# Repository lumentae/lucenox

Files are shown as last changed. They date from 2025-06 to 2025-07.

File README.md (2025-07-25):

# Lucenox

**Lucenox** — *Light in the Darkness*

---

## Overview

Lucenox is a custom mechanical keyboard with hotswappable switches which was inspired by the QWERTZ layout. It also features per key RGB with QMK!

---

## Reason

I made the project just for fun and to see if I could build my own keyboard, because I wanted something that felt exactly like my current keyboard, but in a smaller size.
Also I currently use a membrane keyboard and I thought that highway could give me an opportunity to learn how mechanical keyboards work and switch to a mechanical one.

---

## Technical Details

- **Microcontroller:** Raspberry Pi Pico 
- **Firmware:** QMK
- **Connectivity:** USB wired connection
- **LEDs:** SK6812 RGB underglow LEDs with individual addressability

---

## Front
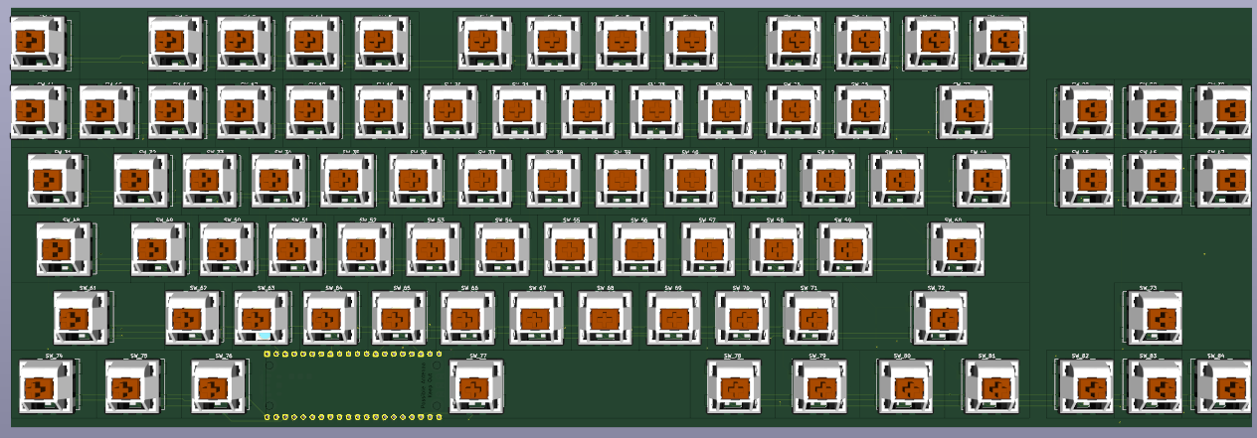
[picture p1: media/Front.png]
Front


## Back
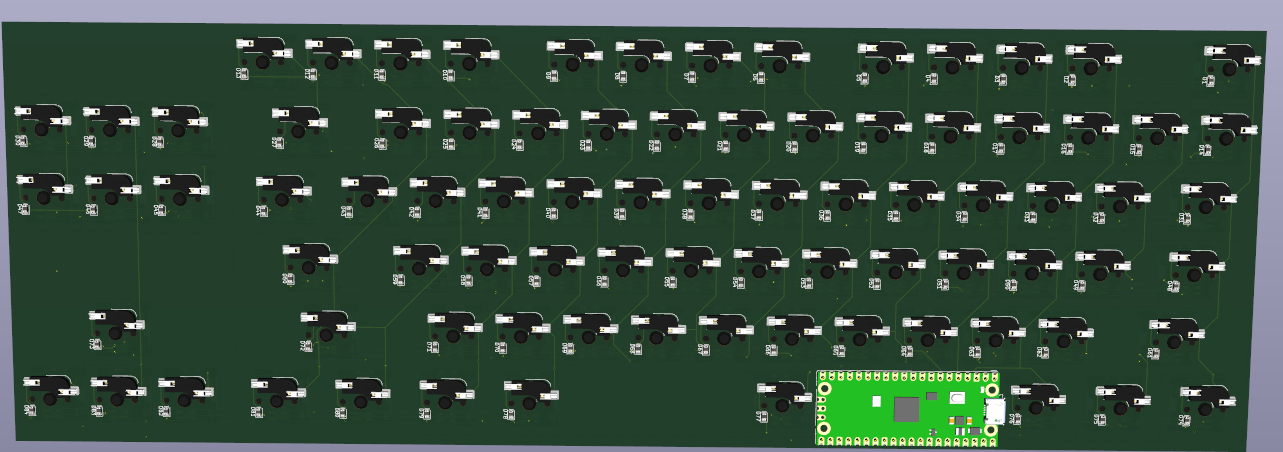
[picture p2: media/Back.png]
Back


## Schematic
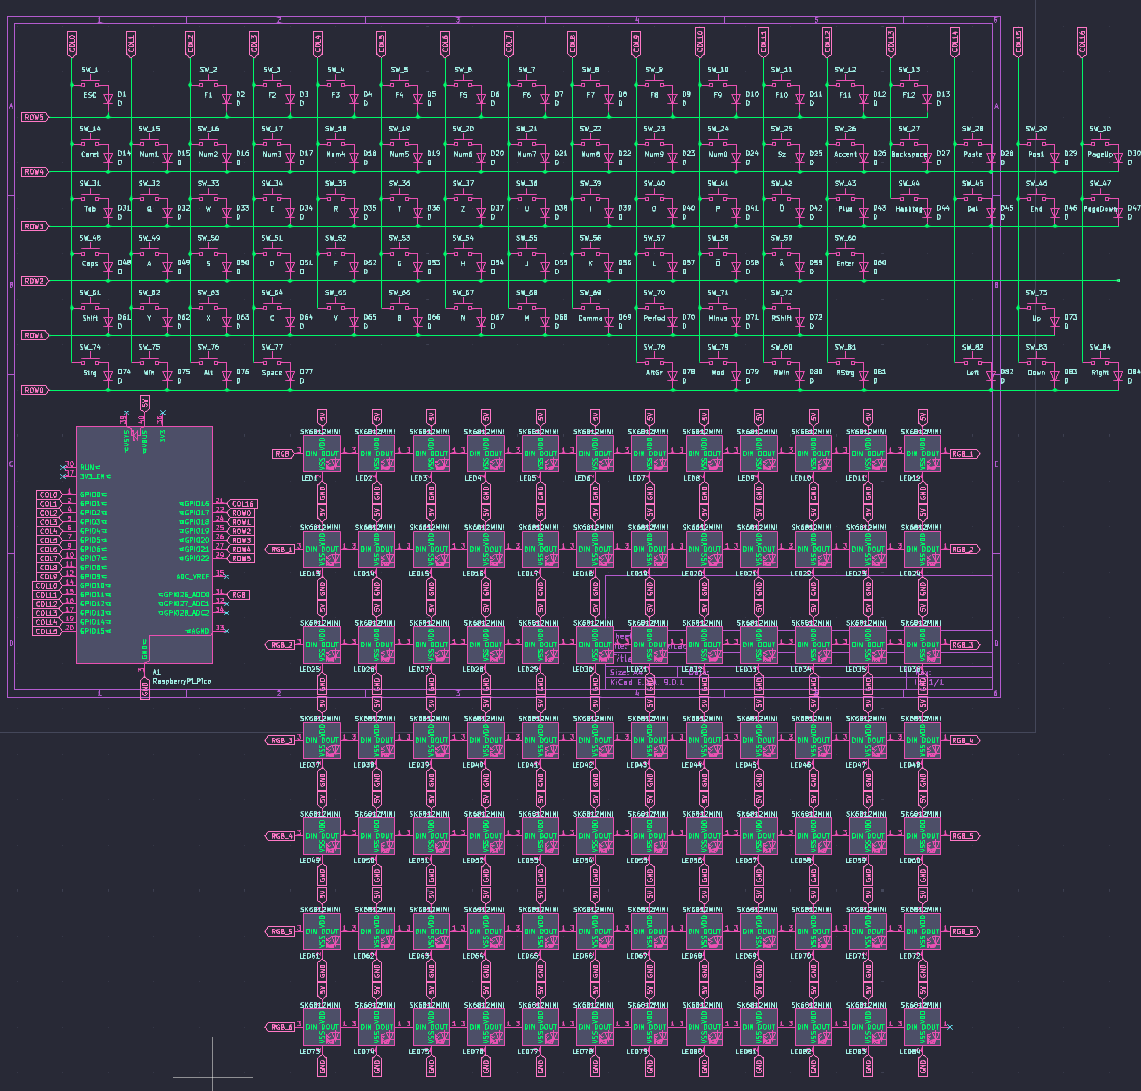
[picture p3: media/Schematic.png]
Schematic


## Case
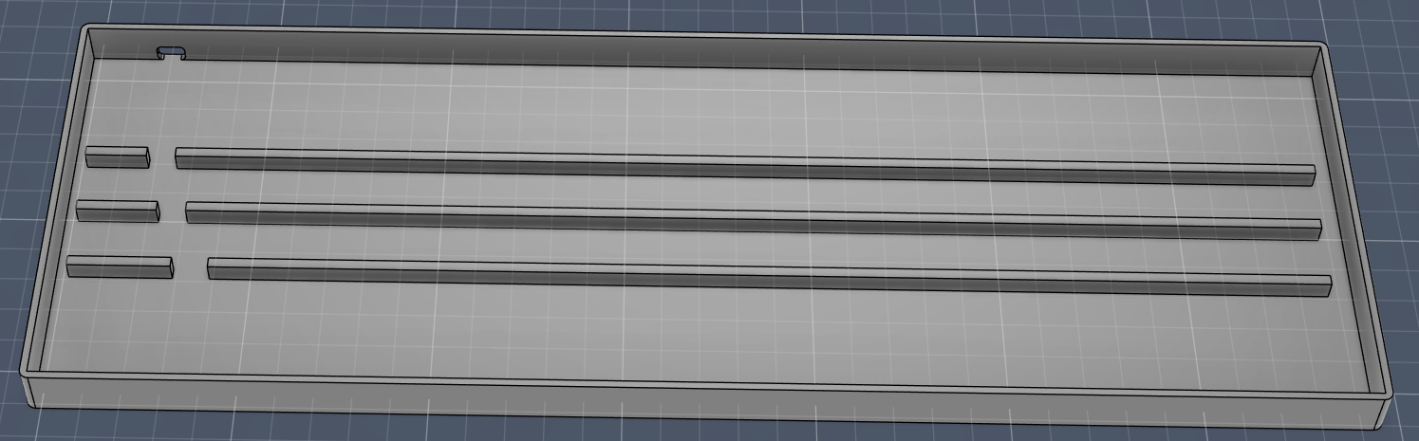
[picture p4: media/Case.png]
Case


## BOM
Quantity  | Name                   | Link                                                                                                     | Price + Shipping
--------- | ---------------------- | -------------------------------------------------------------------------------------------------------- | ----------------
3*30 (90) | Cherry MX Switch       | https://aliexpress.com/item/1005006578935785.html                                                        | 25.17€
84 (90)   | Kailh Hotswap Sockets  | https://candykeys.com/product/kailh-hot-swap-pcb-socket-black                                            | 16.00€
84 (85)   | SK6812MINI LED         | https://lcsc.com/product-detail/RGB-LEDs-Built-in-IC_OPSCO-Optoelectronics-SK6812MINI-E_C5149201.html    | 4.38€
84 (100)  | 0805 Diode (D)         | https://lcsc.com/product-detail/Switching-Diodes_LIZ-Elec-CD4148WSP_C109001.html                         | 1.06€
1         | LCSC Fees              | -                                                                                                        | 9.58€
1         | Raspberry Pi Pico      | https://aliexpress.com/item/1005007384675543.html                                                        | 2.79€
1         | Keycaps                | https://aliexpress.com/item/1005006484466863.html                                                        | 20.99€
1         | PCB (without coupon)   | -                                                                                                        | 88.11€
1         | Total                  |                                                                                                          | 168.08€

### Total
EUR     | USD     | Notes
------- | ------- | -----
168.08€ | 197.44$ | without pcb coupon
148.08€ | 173.95$ | with pcb coupon

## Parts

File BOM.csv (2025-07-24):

Category | Part | Qty | Price € | Link
Switches | Cherry MX Switch | 90 | 25.17€ | https://aliexpress.com/item/1005006578935785.html
Sockets | Kailh Hotswap Sockets | 84 | 16.00€ | https://candykeys.com/product/kailh-hot-swap-pcb-socket-black
LEDs | SK6812MINI LED | 84 | 4.38€ | https://lcsc.com/product-detail/RGB-LEDs-Built-in-IC_OPSCO-Optoelectronics-SK6812MINI-E_C5149201.html
Diodes | 0805 Diode (D) | 84 | 1.06€ | https://lcsc.com/product-detail/Switching-Diodes_LIZ-Elec-CD4148WSP_C109001.html
Fees | LCSC Fees | 1 | 9.58€
MCU | Raspberry Pi Pico | 1 | 2.79€ | https://aliexpress.com/item/1005007384675543.html
Keycaps | Keycaps | 1 | 20.99€ | https://aliexpress.com/item/1005006484466863.html
PCB | PCB (without coupon) | 1 | 88.11€
Total | Total | 1 | 168.08€

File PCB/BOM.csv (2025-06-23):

Id | Designator | Footprint | Quantity | Designation | Supplier and ref
1 | SW_76 | SW_Hotswap_Kailh_MX_1.25u | 1 | Alt
2 | SW_48 | SW_Hotswap_Kailh_MX_1.75u | 1 | Caps
3 | LED71,LED56,LED1,LED78,LED81,LED41,LED16,LED65,LED30,LED24,LED33,LED35,LED73,LED4,LED15,LED62,LED42,LED46,LED14,LED2,LED32,LED23,LED47,LED13,LED66,LED50,LED82,LED20,LED49,LED60,LED7,LED5,LED11,LED63,LED79,LED74,LED21,LED69,LED59,LED57,LED10,LED37,LED3,LED84,LED55,LED6,LED29,LED22,LED68,LED39,LED27,LED45,LED61,LED38,LED25,LED83,LED53,LED17,LED8,LED19,LED58,LED54,LED75,LED77,LED28,LED36,LED52,LED67,LED26,LED76,LED70,LED9,LED40,LED34,LED18,LED48,LED44,LED31,LED80,LED43,LED12,LED64,LED51,LED72 | LED_SK6812MINI_PLCC4_3.5x3.5mm_P1.75mm | 84 | SK6812MINI
4 | SW_12 | SW_Hotswap_Kailh_MX_1.00u | 1 | F11
5 | SW_71 | SW_Hotswap_Kailh_MX_1.00u | 1 | Minus
6 | SW_45 | SW_Hotswap_Kailh_MX_1.00u | 1 | Del
7 | SW_37 | SW_Hotswap_Kailh_MX_1.00u | 1 | Z
8 | SW_16 | SW_Hotswap_Kailh_MX_1.00u | 1 | Num2
9 | SW_60 | SW_Hotswap_Kailh_MX_2.25u | 1 | Enter
10 | SW_14 | SW_Hotswap_Kailh_MX_1.00u | 1 | Caret
11 | SW_72 | SW_Hotswap_Kailh_MX_2.75u | 1 | RShift
12 | SW_7 | SW_Hotswap_Kailh_MX_1.00u | 1 | F6
13 | SW_43 | SW_Hotswap_Kailh_MX_1.00u | 1 | Plus
14 | SW_11 | SW_Hotswap_Kailh_MX_1.00u | 1 | F10
15 | SW_24 | SW_Hotswap_Kailh_MX_1.00u | 1 | Num0
16 | SW_84 | SW_Hotswap_Kailh_MX_1.00u | 1 | Right
17 | SW_34 | SW_Hotswap_Kailh_MX_1.00u | 1 | E
18 | SW_54 | SW_Hotswap_Kailh_MX_1.00u | 1 | H
19 | SW_49 | SW_Hotswap_Kailh_MX_1.00u | 1 | A
20 | SW_19 | SW_Hotswap_Kailh_MX_1.00u | 1 | Num5
21 | SW_8 | SW_Hotswap_Kailh_MX_1.00u | 1 | F7
22 | SW_26 | SW_Hotswap_Kailh_MX_1.00u | 1 | Accent
23 | SW_13 | SW_Hotswap_Kailh_MX_1.00u | 1 | F12
24 | SW_33 | SW_Hotswap_Kailh_MX_1.00u | 1 | W
25 | SW_58 | SW_Hotswap_Kailh_MX_1.00u | 1 | Ö
26 | SW_17 | SW_Hotswap_Kailh_MX_1.00u | 1 | Num3
27 | SW_9 | SW_Hotswap_Kailh_MX_1.00u | 1 | F8
28 | SW_75 | SW_Hotswap_Kailh_MX_1.25u | 1 | Win
29 | SW_79 | SW_Hotswap_Kailh_MX_1.25u | 1 | Mod
30 | SW_62 | SW_Hotswap_Kailh_MX_1.00u | 1 | Y
31 | SW_82 | SW_Hotswap_Kailh_MX_1.00u | 1 | Left
32 | SW_66 | SW_Hotswap_Kailh_MX_1.00u | 1 | B
33 | SW_47 | SW_Hotswap_Kailh_MX_1.00u | 1 | PageDown
34 | SW_35 | SW_Hotswap_Kailh_MX_1.00u | 1 | R
35 | SW_55 | SW_Hotswap_Kailh_MX_1.00u | 1 | J
36 | SW_59 | SW_Hotswap_Kailh_MX_1.00u | 1 | Ä
37 | SW_56 | SW_Hotswap_Kailh_MX_1.00u | 1 | K
38 | SW_39 | SW_Hotswap_Kailh_MX_1.00u | 1 | I
39 | SW_28 | SW_Hotswap_Kailh_MX_1.00u | 1 | Paste
40 | SW_65 | SW_Hotswap_Kailh_MX_1.00u | 1 | V
41 | SW_57 | SW_Hotswap_Kailh_MX_1.00u | 1 | L
42 | SW_30 | SW_Hotswap_Kailh_MX_1.00u | 1 | PageUp
43 | SW_36 | SW_Hotswap_Kailh_MX_1.00u | 1 | T
44 | SW_52 | SW_Hotswap_Kailh_MX_1.00u | 1 | F
45 | SW_5 | SW_Hotswap_Kailh_MX_1.00u | 1 | F4
46 | SW_63 | SW_Hotswap_Kailh_MX_1.00u | 1 | X
47 | SW_41 | SW_Hotswap_Kailh_MX_1.00u | 1 | P
48 | SW_74 | SW_Hotswap_Kailh_MX_1.25u | 1 | Strg
49 | SW_51 | SW_Hotswap_Kailh_MX_1.00u | 1 | D
50 | SW_2 | SW_Hotswap_Kailh_MX_1.00u | 1 | F1
51 | SW_61 | SW_Hotswap_Kailh_MX_2.25u | 1 | Shift
52 | SW_78 | SW_Hotswap_Kailh_MX_1.25u | 1 | AltGr
53 | SW_68 | SW_Hotswap_Kailh_MX_1.00u | 1 | M
54 | SW_53 | SW_Hotswap_Kailh_MX_1.00u | 1 | G
55 | SW_69 | SW_Hotswap_Kailh_MX_1.00u | 1 | Comma
56 | SW_29 | SW_Hotswap_Kailh_MX_1.00u | 1 | Pos1
57 | SW_50 | SW_Hotswap_Kailh_MX_1.00u | 1 | S
58 | SW_20 | SW_Hotswap_Kailh_MX_1.00u | 1 | Num6
59 | SW_15 | SW_Hotswap_Kailh_MX_1.00u | 1 | Num1
60 | SW_32 | SW_Hotswap_Kailh_MX_1.00u | 1 | Q
61 | SW_1 | SW_Hotswap_Kailh_MX_1.00u | 1 | ESC
62 | SW_83 | SW_Hotswap_Kailh_MX_1.00u | 1 | Down
63 | SW_81 | SW_Hotswap_Kailh_MX_1.25u | 1 | RStrg
64 | SW_44 | SW_Hotswap_Kailh_MX_1.50u | 1 | Hashtag
65 | SW_23 | SW_Hotswap_Kailh_MX_1.00u | 1 | Num9
66 | SW_18 | SW_Hotswap_Kailh_MX_1.00u | 1 | Num4
67 | SW_40 | SW_Hotswap_Kailh_MX_1.00u | 1 | O
68 | SW_67 | SW_Hotswap_Kailh_MX_1.00u | 1 | N
69 | SW_3 | SW_Hotswap_Kailh_MX_1.00u | 1 | F2
70 | SW_42 | SW_Hotswap_Kailh_MX_1.00u | 1 | Ü
71 | SW_27 | SW_Hotswap_Kailh_MX_2.00u | 1 | Backspace
72 | SW_4 | SW_Hotswap_Kailh_MX_1.00u | 1 | F3
73 | SW_64 | SW_Hotswap_Kailh_MX_1.00u | 1 | C
74 | SW_80 | SW_Hotswap_Kailh_MX_1.25u | 1 | RWin
75 | SW_6 | SW_Hotswap_Kailh_MX_1.00u | 1 | F5
76 | SW_21 | SW_Hotswap_Kailh_MX_1.00u | 1 | Num7
77 | SW_77 | SW_Hotswap_Kailh_MX_6.25u | 1 | Space
78 | SW_73 | SW_Hotswap_Kailh_MX_1.00u | 1 | Up
79 | SW_46 | SW_Hotswap_Kailh_MX_1.00u | 1 | End
80 | SW_31 | SW_Hotswap_Kailh_MX_1.50u | 1 | Tab
81 | SW_38 | SW_Hotswap_Kailh_MX_1.00u | 1 | U
82 | SW_25 | SW_Hotswap_Kailh_MX_1.00u | 1 | Sz
83 | SW_10 | SW_Hotswap_Kailh_MX_1.00u | 1 | F9
84 | SW_22 | SW_Hotswap_Kailh_MX_1.00u | 1 | Num8
85 | SW_70 | SW_Hotswap_Kailh_MX_1.00u | 1 | Period
86 | D78,D36,D22,D40,D52,D26,D49,D19,D83,D5,D72,D44,D39,D6,D76,D82,D38,D74,D4,D68,D12,D48,D80,D28,D59,D81,D45,D66,D58,D2,D62,D84,D23,D10,D24,D35,D56,D31,D18,D8,D65,D64,D1,D73,D46,D30,D67,D20,D77,D63,D16,D69,D21,D3,D60,D70,D79,D61,D27,D55,D15,D75,D11,D71,D34,D47,D41,D17,D37,D43,D13,D29,D14,D42,D32,D25,D53,D7,D33,D50,D9,D51,D57,D54 | D_0805_2012Metric | 84 | D
87 | A1 | RaspberryPi_Pico_Common_THT | 1 | RaspberryPi_Pico

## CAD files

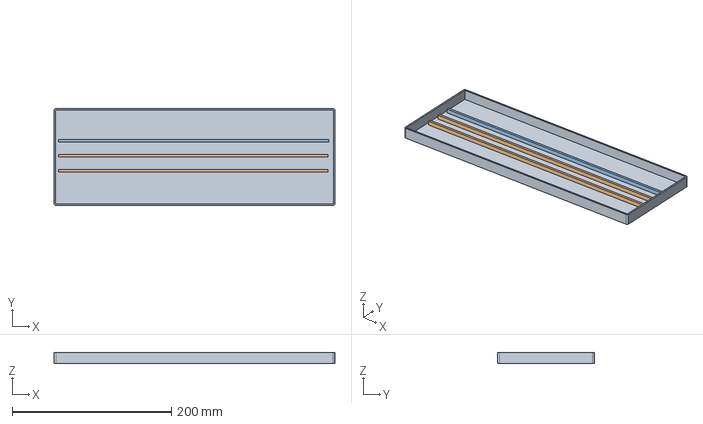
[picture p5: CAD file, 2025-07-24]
CAD/Case.step
353.0 x 122.0 x 14.0 mm

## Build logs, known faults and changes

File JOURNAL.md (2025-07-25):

---
title: "Lucenox"
author: "lumentae"
description: "Lucenox is a 75% mechanical keyboard with 84 keys, RGB underglow, and built for QWERTZ users."
created_at: "2025-06-18"
---

Total Time Spent: 19h

# 18.06
I started working on the schematic, which I got done quickly but I needed to research how keyboard matrices work and found [this](https://www.youtube.com/watch?v=7LyziNdFlew) video by Joe Scotto.

After 3h of brainstorming and designing the schematic, I moved on to the pcb.
This is what took me the longest because I tried to route it manually.
Schematic

Time spent: 6h

# 19.06
Today I remembered that I have Freerouting installed, so I used it for it's autorouting feature and it saved me many hours of painfully placing vias and routes.
I also adjusted the layout and mcu position.
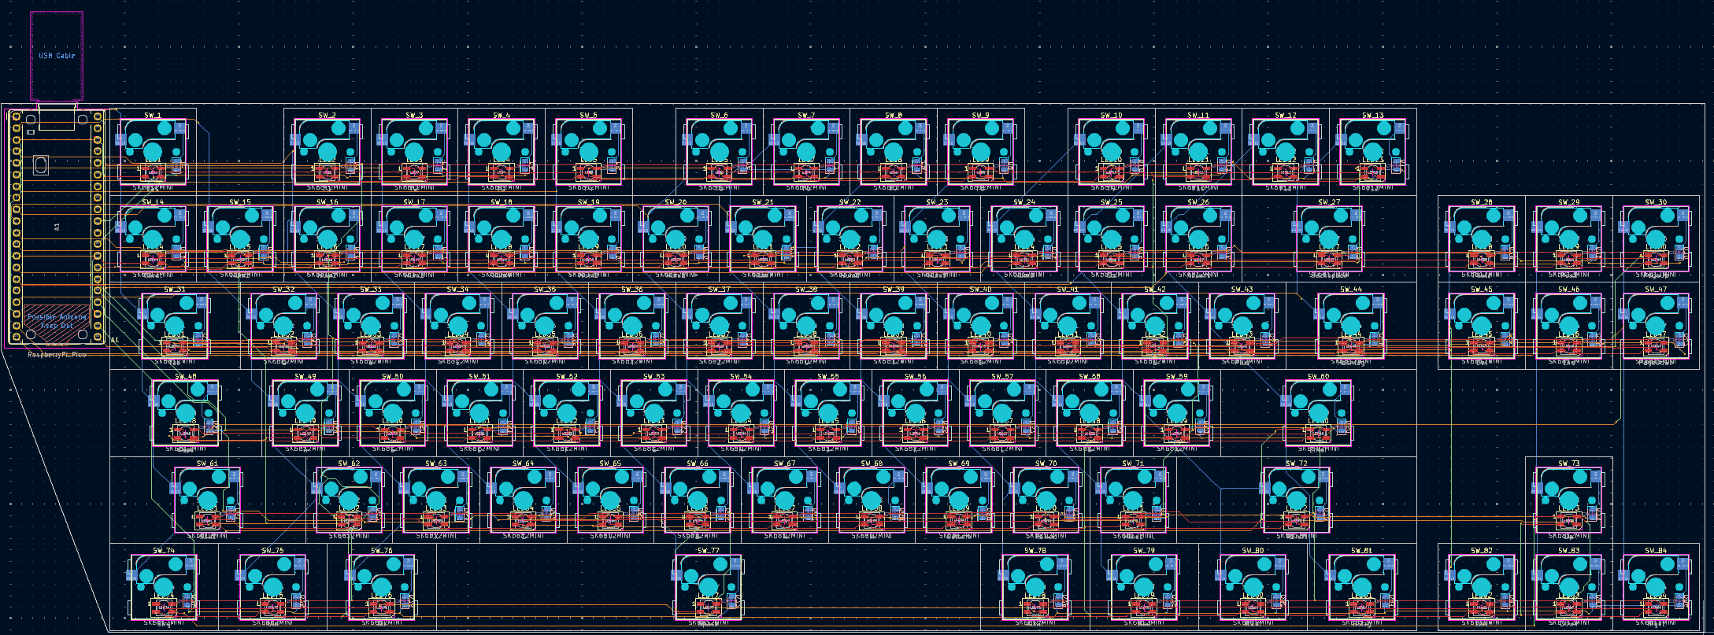
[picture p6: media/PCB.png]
PCB


Time spent: 2h

# 22.06
I placed the mcu under the space key, so that the pcb doesn't look so weird.
I'll need a longer usb cable now 🥲
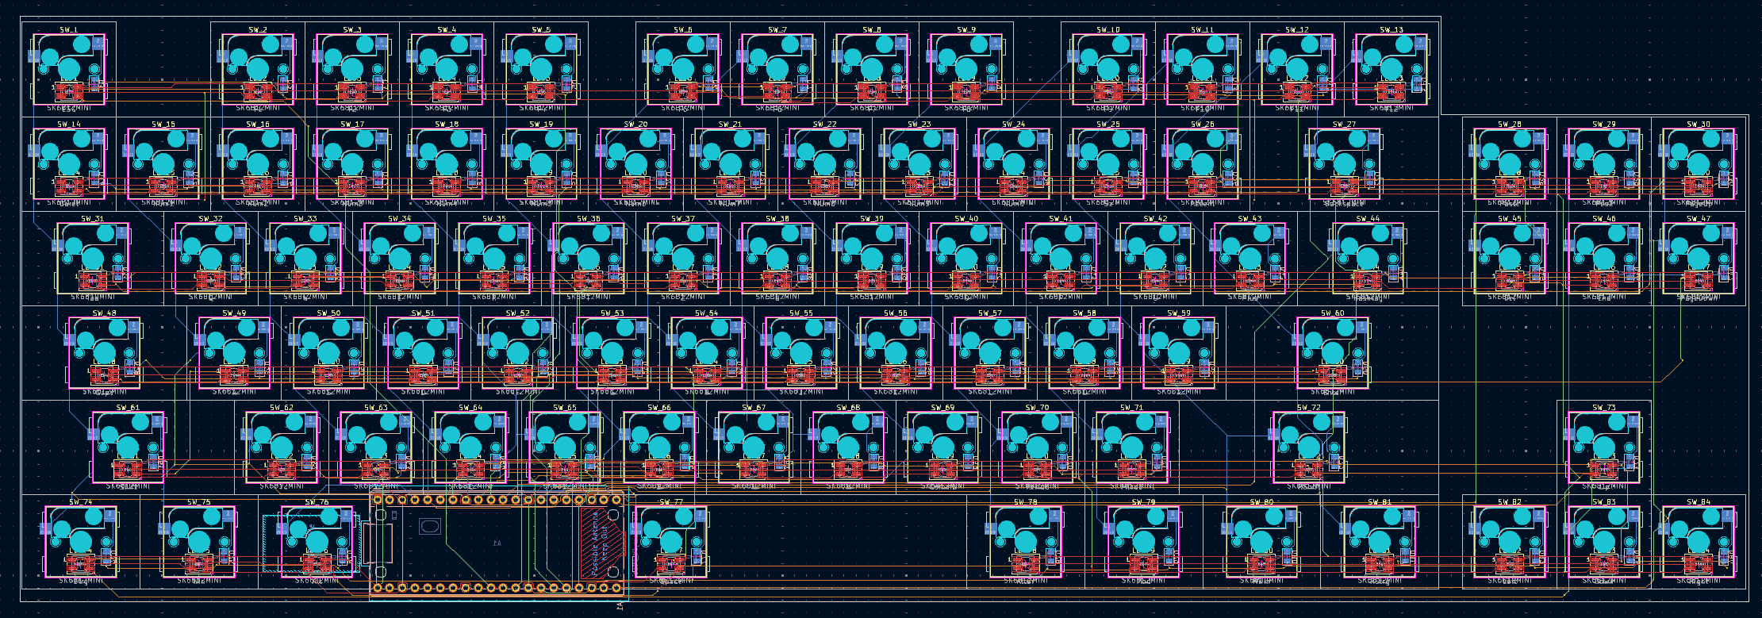
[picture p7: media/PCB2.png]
PCB2


Time spent: 1h

# 23.06
Today I worked on polishing the repo and uploading all files I used for creating the project.
Tomorrow I will work on the cad model

Time spent: 3h

# 24.07
I finished the model after 1 month because I didn't have enough motivation to finish it.
Also I didn't make a front plate because I like to look at the pcb
Case

I also modified the pcb to not have that cut out in the top right corner
PCB_Final

I finally finished the bom and I only need to make the firmware

Time spent: 4h

# 25.07
After a long trial and error session with QMK I finally managed that the firmware is building.
The QMK docs are not very good at explaining how to make your own keyboard...

Time spent: 3h

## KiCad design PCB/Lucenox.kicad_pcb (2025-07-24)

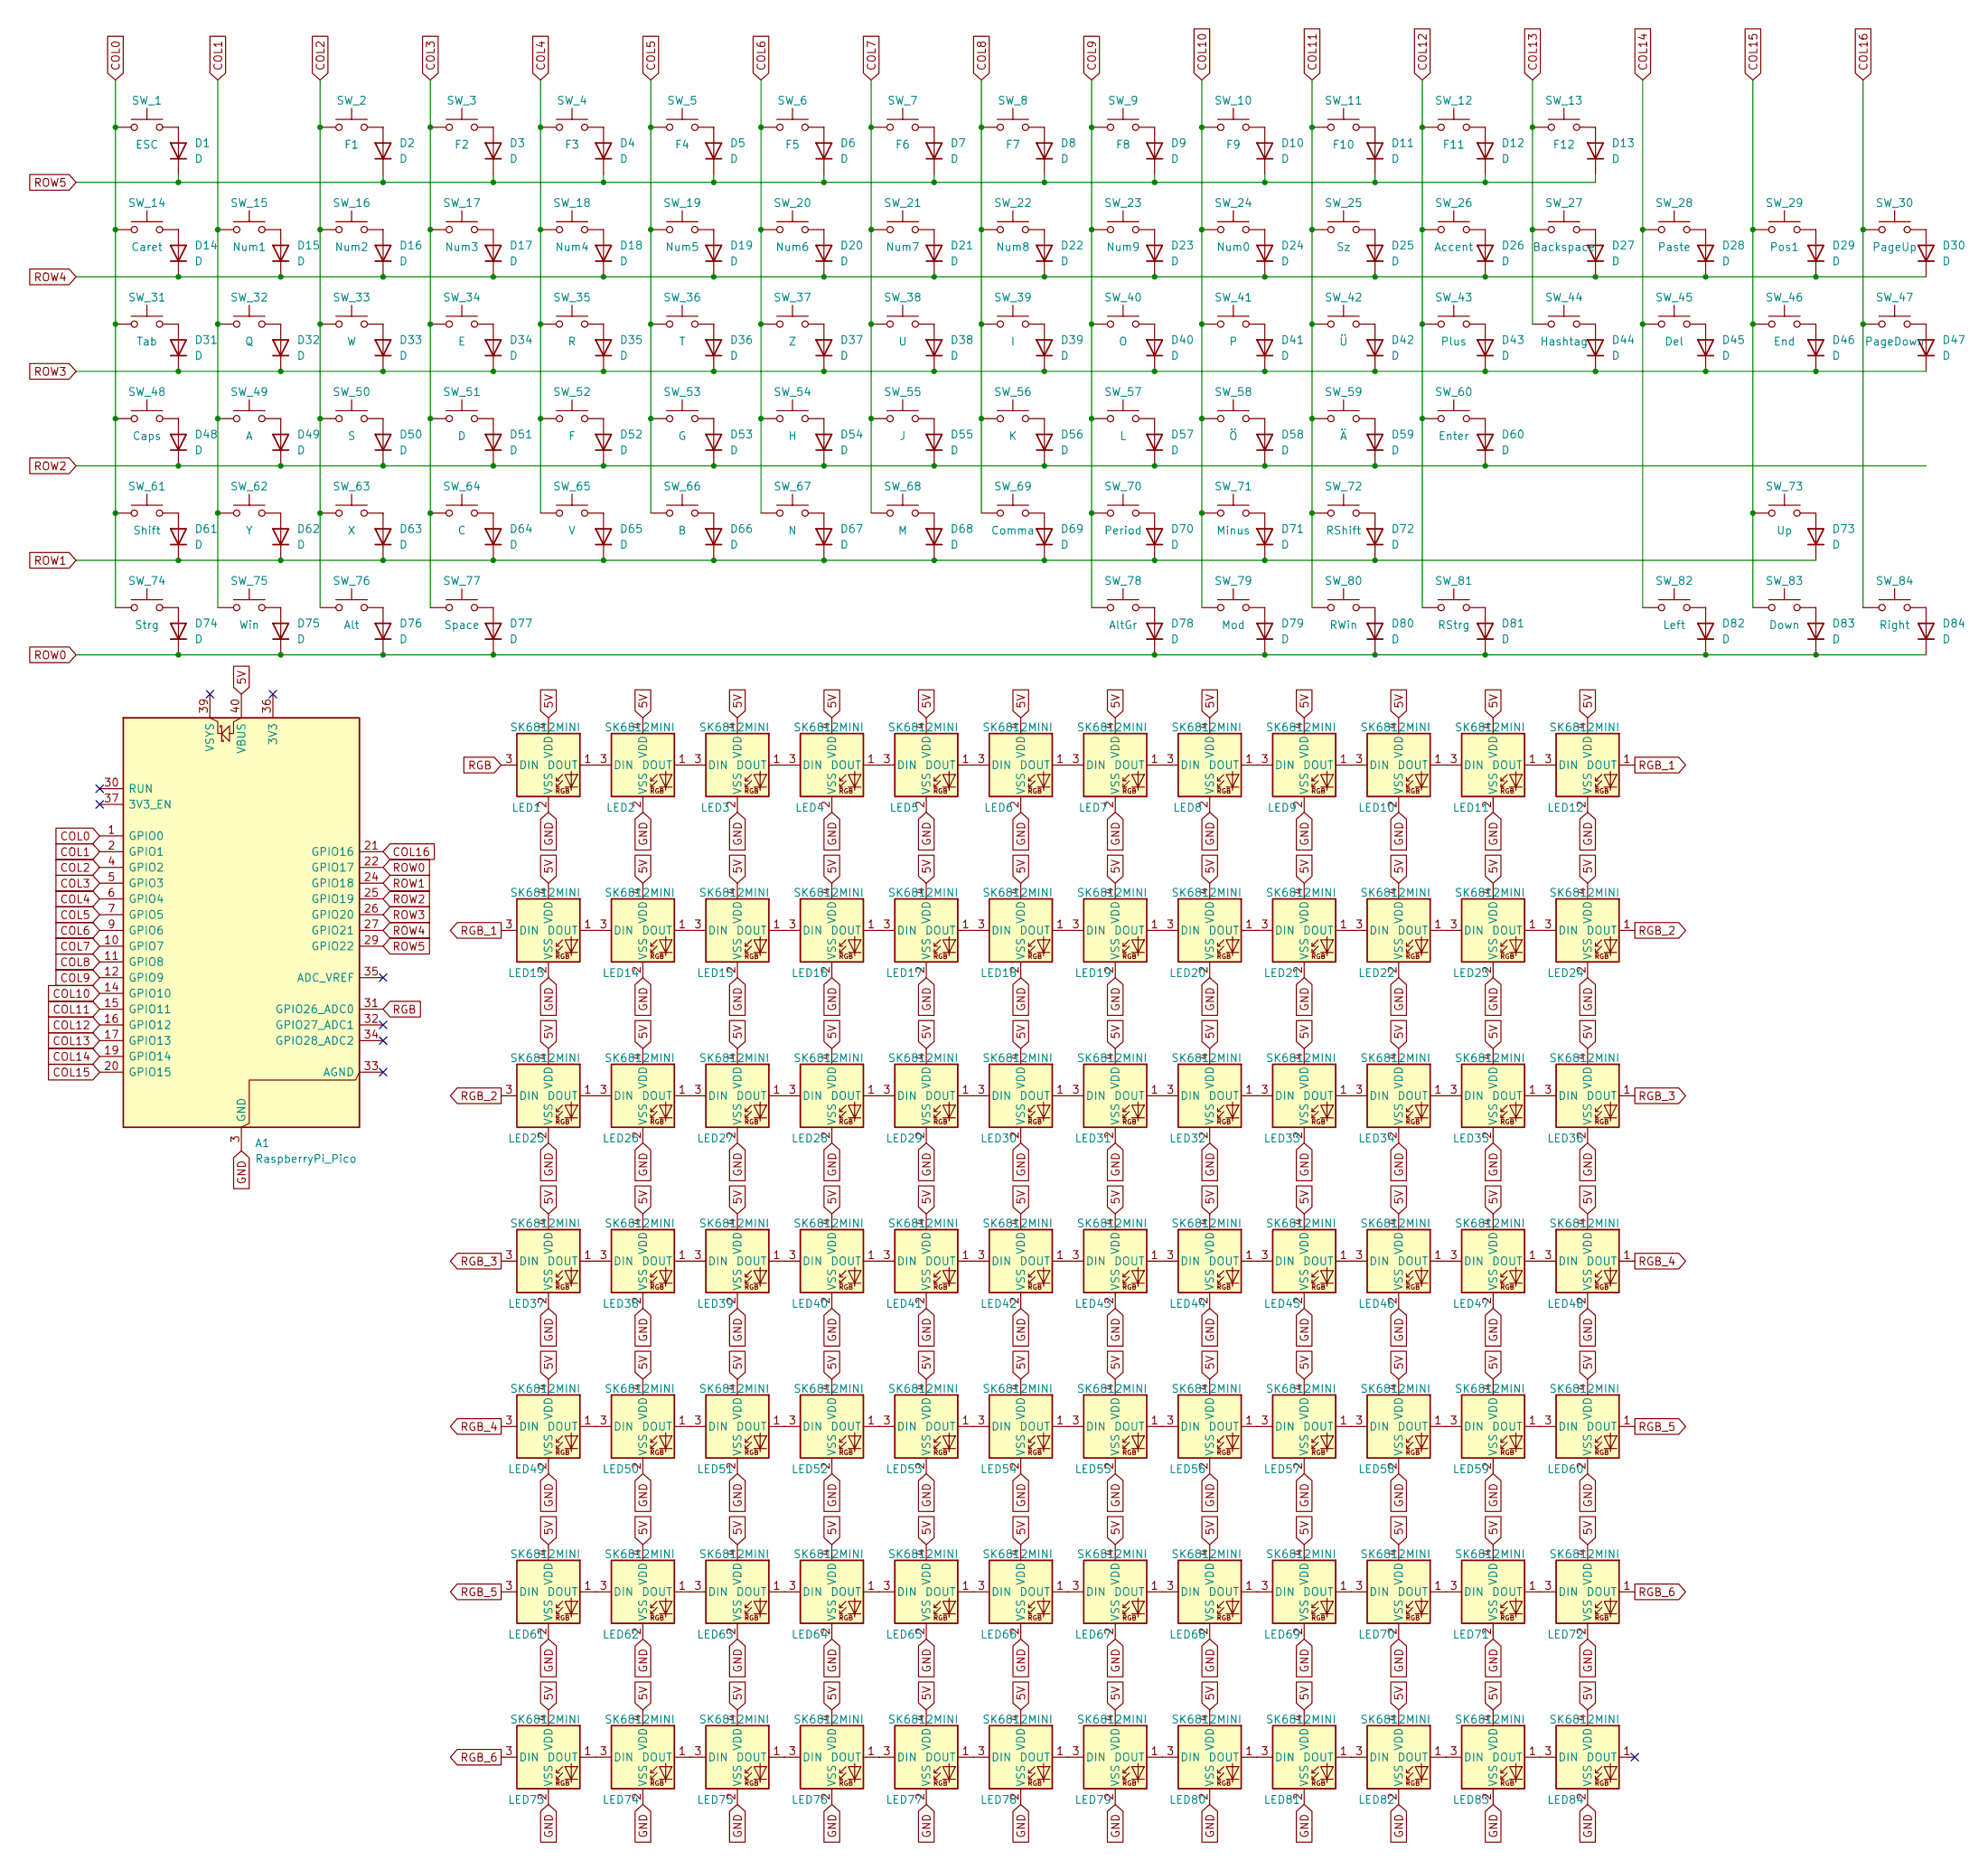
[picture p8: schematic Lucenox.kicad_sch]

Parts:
A1: RaspberryPi_Pico; RaspberryPi_Pico_Common_THT
D1, D2, D3, D4, D5, D6, D7, D8, D9, D10, D11, D12, D13, D14, D15, D16, D17, D18, D19, D20, D21, D22, D23, D24, D25, D26, D27, D28, D29, D30, D31, D32, D33, D34, D35, D36, D37, D38, D39, D40, D41, D42, D43, D44, D45, D46, D47, D48, D49, D50, D51, D52, D53, D54, D55, D56, D57, D58, D59, D60, D61, D62, D63, D64, D65, D66, D67, D68, D69, D70, D71, D72, D73, D74, D75, D76, D77, D78, D79, D80, D81, D82, D83, D84: D; D_0805_2012Metric
LED1, LED2, LED3, LED4, LED5, LED6, LED7, LED8, LED9, LED10, LED11, LED12, LED13, LED14, LED15, LED16, LED17, LED18, LED19, LED20, LED21, LED22, LED23, LED24, LED25, LED26, LED27, LED28, LED29, LED30, LED31, LED32, LED33, LED34, LED35, LED36, LED37, LED38, LED39, LED40, LED41, LED42, LED43, LED44, LED45, LED46, LED47, LED48, LED49, LED50, LED51, LED52, LED53, LED54, LED55, LED56, LED57, LED58, LED59, LED60, LED61, LED62, LED63, LED64, LED65, LED66, LED67, LED68, LED69, LED70, LED71, LED72, LED73, LED74, LED75, LED76, LED77, LED78, LED79, LED80, LED81, LED82, LED83, LED84: SK6812MINI; LED_SK6812MINI_PLCC4_3.5x3.5mm_P1.75mm
SW_1: ESC; SW_Hotswap_Kailh_MX_1.00u
SW_2: F1; SW_Hotswap_Kailh_MX_1.00u
SW_3: F2; SW_Hotswap_Kailh_MX_1.00u
SW_4: F3; SW_Hotswap_Kailh_MX_1.00u
SW_5: F4; SW_Hotswap_Kailh_MX_1.00u
SW_6: F5; SW_Hotswap_Kailh_MX_1.00u
SW_7: F6; SW_Hotswap_Kailh_MX_1.00u
SW_8: F7; SW_Hotswap_Kailh_MX_1.00u
SW_9: F8; SW_Hotswap_Kailh_MX_1.00u
SW_10: F9; SW_Hotswap_Kailh_MX_1.00u
SW_11: F10; SW_Hotswap_Kailh_MX_1.00u
SW_12: F11; SW_Hotswap_Kailh_MX_1.00u
SW_13: F12; SW_Hotswap_Kailh_MX_1.00u
SW_14: Caret; SW_Hotswap_Kailh_MX_1.00u
SW_15: Num1; SW_Hotswap_Kailh_MX_1.00u
SW_16: Num2; SW_Hotswap_Kailh_MX_1.00u
SW_17: Num3; SW_Hotswap_Kailh_MX_1.00u
SW_18: Num4; SW_Hotswap_Kailh_MX_1.00u
SW_19: Num5; SW_Hotswap_Kailh_MX_1.00u
SW_20: Num6; SW_Hotswap_Kailh_MX_1.00u
SW_21: Num7; SW_Hotswap_Kailh_MX_1.00u
SW_22: Num8; SW_Hotswap_Kailh_MX_1.00u
SW_23: Num9; SW_Hotswap_Kailh_MX_1.00u
SW_24: Num0; SW_Hotswap_Kailh_MX_1.00u
SW_25: Sz; SW_Hotswap_Kailh_MX_1.00u
SW_26: Accent; SW_Hotswap_Kailh_MX_1.00u
SW_27: Backspace; SW_Hotswap_Kailh_MX_2.00u
SW_28: Paste; SW_Hotswap_Kailh_MX_1.00u
SW_29: Pos1; SW_Hotswap_Kailh_MX_1.00u
SW_30: PageUp; SW_Hotswap_Kailh_MX_1.00u
SW_31: Tab; SW_Hotswap_Kailh_MX_1.50u
SW_32: Q; SW_Hotswap_Kailh_MX_1.00u
SW_33: W; SW_Hotswap_Kailh_MX_1.00u
SW_34: E; SW_Hotswap_Kailh_MX_1.00u
SW_35: R; SW_Hotswap_Kailh_MX_1.00u
SW_36: T; SW_Hotswap_Kailh_MX_1.00u
SW_37: Z; SW_Hotswap_Kailh_MX_1.00u
SW_38: U; SW_Hotswap_Kailh_MX_1.00u
SW_39: I; SW_Hotswap_Kailh_MX_1.00u
SW_40: O; SW_Hotswap_Kailh_MX_1.00u
SW_41: P; SW_Hotswap_Kailh_MX_1.00u
SW_42: Ü; SW_Hotswap_Kailh_MX_1.00u
SW_43: Plus; SW_Hotswap_Kailh_MX_1.00u
SW_44: Hashtag; SW_Hotswap_Kailh_MX_1.50u
SW_45: Del; SW_Hotswap_Kailh_MX_1.00u
SW_46: End; SW_Hotswap_Kailh_MX_1.00u
SW_47: PageDown; SW_Hotswap_Kailh_MX_1.00u
SW_48: Caps; SW_Hotswap_Kailh_MX_1.75u
SW_49: A; SW_Hotswap_Kailh_MX_1.00u
SW_50: S; SW_Hotswap_Kailh_MX_1.00u
SW_51: D; SW_Hotswap_Kailh_MX_1.00u
SW_52: F; SW_Hotswap_Kailh_MX_1.00u
SW_53: G; SW_Hotswap_Kailh_MX_1.00u
SW_54: H; SW_Hotswap_Kailh_MX_1.00u
SW_55: J; SW_Hotswap_Kailh_MX_1.00u
SW_56: K; SW_Hotswap_Kailh_MX_1.00u
SW_57: L; SW_Hotswap_Kailh_MX_1.00u
SW_58: Ö; SW_Hotswap_Kailh_MX_1.00u
SW_59: Ä; SW_Hotswap_Kailh_MX_1.00u
SW_60: Enter; SW_Hotswap_Kailh_MX_2.25u
SW_61: Shift; SW_Hotswap_Kailh_MX_2.25u
SW_62: Y; SW_Hotswap_Kailh_MX_1.00u
SW_63: X; SW_Hotswap_Kailh_MX_1.00u
SW_64: C; SW_Hotswap_Kailh_MX_1.00u
SW_65: V; SW_Hotswap_Kailh_MX_1.00u
SW_66: B; SW_Hotswap_Kailh_MX_1.00u
SW_67: N; SW_Hotswap_Kailh_MX_1.00u
SW_68: M; SW_Hotswap_Kailh_MX_1.00u
SW_69: Comma; SW_Hotswap_Kailh_MX_1.00u
SW_70: Period; SW_Hotswap_Kailh_MX_1.00u
SW_71: Minus; SW_Hotswap_Kailh_MX_1.00u
SW_72: RShift; SW_Hotswap_Kailh_MX_2.75u
SW_73: Up; SW_Hotswap_Kailh_MX_1.00u
SW_74: Strg; SW_Hotswap_Kailh_MX_1.25u
SW_75: Win; SW_Hotswap_Kailh_MX_1.25u
SW_76: Alt; SW_Hotswap_Kailh_MX_1.25u
SW_77: Space; SW_Hotswap_Kailh_MX_6.25u
SW_78: AltGr; SW_Hotswap_Kailh_MX_1.25u
SW_79: Mod; SW_Hotswap_Kailh_MX_1.25u
SW_80: RWin; SW_Hotswap_Kailh_MX_1.25u
SW_81: RStrg; SW_Hotswap_Kailh_MX_1.25u
SW_82: Left; SW_Hotswap_Kailh_MX_1.00u
SW_83: Down; SW_Hotswap_Kailh_MX_1.00u
SW_84: Right; SW_Hotswap_Kailh_MX_1.00u

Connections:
5V: A1.40 (VBUS), LED1.4 (VDD), LED2.4 (VDD), LED3.4 (VDD), LED4.4 (VDD), LED5.4 (VDD), LED6.4 (VDD), LED7.4 (VDD), LED8.4 (VDD), LED9.4 (VDD), LED10.4 (VDD), LED11.4 (VDD), LED12.4 (VDD), LED13.4 (VDD), LED14.4 (VDD), LED15.4 (VDD), LED16.4 (VDD), LED17.4 (VDD), LED18.4 (VDD), LED19.4 (VDD), LED20.4 (VDD), LED21.4 (VDD), LED22.4 (VDD), LED23.4 (VDD), LED24.4 (VDD), LED25.4 (VDD), LED26.4 (VDD), LED27.4 (VDD), LED28.4 (VDD), LED29.4 (VDD), LED30.4 (VDD), LED31.4 (VDD), LED32.4 (VDD), LED33.4 (VDD), LED34.4 (VDD), LED35.4 (VDD), LED36.4 (VDD), LED37.4 (VDD), LED38.4 (VDD), LED39.4 (VDD), LED40.4 (VDD), LED41.4 (VDD), LED42.4 (VDD), LED43.4 (VDD), LED44.4 (VDD), LED45.4 (VDD), LED46.4 (VDD), LED47.4 (VDD), LED48.4 (VDD), LED49.4 (VDD), LED50.4 (VDD), LED51.4 (VDD), LED52.4 (VDD), LED53.4 (VDD), LED54.4 (VDD), LED55.4 (VDD), LED56.4 (VDD), LED57.4 (VDD), LED58.4 (VDD), LED59.4 (VDD), LED60.4 (VDD), LED61.4 (VDD), LED62.4 (VDD), LED63.4 (VDD), LED64.4 (VDD), LED65.4 (VDD), LED66.4 (VDD), LED67.4 (VDD), LED68.4 (VDD), LED69.4 (VDD), LED70.4 (VDD), LED71.4 (VDD), LED72.4 (VDD), LED73.4 (VDD), LED74.4 (VDD), LED75.4 (VDD), LED76.4 (VDD), LED77.4 (VDD), LED78.4 (VDD), LED79.4 (VDD), LED80.4 (VDD), LED81.4 (VDD), LED82.4 (VDD), LED83.4 (VDD), LED84.4 (VDD)
COL0: A1.1 (GPIO0), SW_1.1, SW_14.1, SW_31.1, SW_48.1, SW_61.1, SW_74.1
COL1: A1.2 (GPIO1), SW_15.1, SW_32.1, SW_49.1, SW_62.1, SW_75.1
COL2: A1.4 (GPIO2), SW_2.1, SW_16.1, SW_33.1, SW_50.1, SW_63.1, SW_76.1
COL3: A1.5 (GPIO3), SW_3.1, SW_17.1, SW_34.1, SW_51.1, SW_64.1, SW_77.1
COL4: A1.6 (GPIO4), SW_4.1, SW_18.1, SW_35.1, SW_52.1, SW_65.1
COL5: A1.7 (GPIO5), SW_5.1, SW_19.1, SW_36.1, SW_53.1, SW_66.1
COL6: A1.9 (GPIO6), SW_6.1, SW_20.1, SW_37.1, SW_54.1, SW_67.1
COL7: A1.10 (GPIO7), SW_7.1, SW_21.1, SW_38.1, SW_55.1, SW_68.1
COL8: A1.11 (GPIO8), SW_8.1, SW_22.1, SW_39.1, SW_56.1, SW_69.1
COL9: A1.12 (GPIO9), SW_9.1, SW_23.1, SW_40.1, SW_57.1, SW_70.1, SW_78.1
COL10: A1.14 (GPIO10), SW_10.1, SW_24.1, SW_41.1, SW_58.1, SW_71.1, SW_79.1
COL11: A1.15 (GPIO11), SW_11.1, SW_25.1, SW_42.1, SW_59.1, SW_72.1, SW_80.1
COL12: A1.16 (GPIO12), SW_12.1, SW_26.1, SW_43.1, SW_60.1, SW_81.1
COL13: A1.17 (GPIO13), SW_13.1, SW_27.1, SW_44.1
COL14: A1.19 (GPIO14), SW_28.1, SW_45.1, SW_82.1
COL15: A1.20 (GPIO15), SW_29.1, SW_46.1, SW_73.1, SW_83.1
COL16: A1.21 (GPIO16), SW_30.1, SW_47.1, SW_84.1
GND: A1.3 (GND), A1.8 (GND), A1.13 (GND), A1.18 (GND), A1.23 (GND), A1.28 (GND), A1.38 (GND), LED1.2 (VSS), LED2.2 (VSS), LED3.2 (VSS), LED4.2 (VSS), LED5.2 (VSS), LED6.2 (VSS), LED7.2 (VSS), LED8.2 (VSS), LED9.2 (VSS), LED10.2 (VSS), LED11.2 (VSS), LED12.2 (VSS), LED13.2 (VSS), LED14.2 (VSS), LED15.2 (VSS), LED16.2 (VSS), LED17.2 (VSS), LED18.2 (VSS), LED19.2 (VSS), LED20.2 (VSS), LED21.2 (VSS), LED22.2 (VSS), LED23.2 (VSS), LED24.2 (VSS), LED25.2 (VSS), LED26.2 (VSS), LED27.2 (VSS), LED28.2 (VSS), LED29.2 (VSS), LED30.2 (VSS), LED31.2 (VSS), LED32.2 (VSS), LED33.2 (VSS), LED34.2 (VSS), LED35.2 (VSS), LED36.2 (VSS), LED37.2 (VSS), LED38.2 (VSS), LED39.2 (VSS), LED40.2 (VSS), LED41.2 (VSS), LED42.2 (VSS), LED43.2 (VSS), LED44.2 (VSS), LED45.2 (VSS), LED46.2 (VSS), LED47.2 (VSS), LED48.2 (VSS), LED49.2 (VSS), LED50.2 (VSS), LED51.2 (VSS), LED52.2 (VSS), LED53.2 (VSS), LED54.2 (VSS), LED55.2 (VSS), LED56.2 (VSS), LED57.2 (VSS), LED58.2 (VSS), LED59.2 (VSS), LED60.2 (VSS), LED61.2 (VSS), LED62.2 (VSS), LED63.2 (VSS), LED64.2 (VSS), LED65.2 (VSS), LED66.2 (VSS), LED67.2 (VSS), LED68.2 (VSS), LED69.2 (VSS), LED70.2 (VSS), LED71.2 (VSS), LED72.2 (VSS), LED73.2 (VSS), LED74.2 (VSS), LED75.2 (VSS), LED76.2 (VSS), LED77.2 (VSS), LED78.2 (VSS), LED79.2 (VSS), LED80.2 (VSS), LED81.2 (VSS), LED82.2 (VSS), LED83.2 (VSS), LED84.2 (VSS)
unnamed: D1.2 (A), SW_1.2
unnamed: D2.2 (A), SW_2.2
unnamed: D3.2 (A), SW_3.2
unnamed: D4.2 (A), SW_4.2
unnamed: D5.2 (A), SW_5.2
unnamed: D6.2 (A), SW_6.2
unnamed: D7.2 (A), SW_7.2
unnamed: D8.2 (A), SW_8.2
unnamed: D9.2 (A), SW_9.2
unnamed: D10.2 (A), SW_10.2
unnamed: D11.2 (A), SW_11.2
unnamed: D12.2 (A), SW_12.2
unnamed: D13.2 (A), SW_13.2
unnamed: D14.2 (A), SW_14.2
unnamed: D15.2 (A), SW_15.2
unnamed: D16.2 (A), SW_16.2
unnamed: D17.2 (A), SW_17.2
unnamed: D18.2 (A), SW_18.2
unnamed: D19.2 (A), SW_19.2
unnamed: D20.2 (A), SW_20.2
unnamed: D21.2 (A), SW_21.2
unnamed: D22.2 (A), SW_22.2
unnamed: D23.2 (A), SW_23.2
unnamed: D24.2 (A), SW_24.2
unnamed: D25.2 (A), SW_25.2
unnamed: D26.2 (A), SW_26.2
unnamed: D27.2 (A), SW_27.2
unnamed: D28.2 (A), SW_28.2
unnamed: D29.2 (A), SW_29.2
unnamed: D30.2 (A), SW_30.2
unnamed: D31.2 (A), SW_31.2
unnamed: D32.2 (A), SW_32.2
unnamed: D33.2 (A), SW_33.2
unnamed: D34.2 (A), SW_34.2
unnamed: D35.2 (A), SW_35.2
unnamed: D36.2 (A), SW_36.2
unnamed: D37.2 (A), SW_37.2
unnamed: D38.2 (A), SW_38.2
unnamed: D39.2 (A), SW_39.2
unnamed: D40.2 (A), SW_40.2
unnamed: D41.2 (A), SW_41.2
unnamed: D42.2 (A), SW_42.2
unnamed: D43.2 (A), SW_43.2
unnamed: D44.2 (A), SW_44.2
unnamed: D45.2 (A), SW_45.2
unnamed: D46.2 (A), SW_46.2
unnamed: D47.2 (A), SW_47.2
unnamed: D48.2 (A), SW_48.2
unnamed: D49.2 (A), SW_49.2
unnamed: D50.2 (A), SW_50.2
unnamed: D51.2 (A), SW_51.2
unnamed: D52.2 (A), SW_52.2
unnamed: D53.2 (A), SW_53.2
unnamed: D54.2 (A), SW_54.2
unnamed: D55.2 (A), SW_55.2
unnamed: D56.2 (A), SW_56.2
unnamed: D57.2 (A), SW_57.2
unnamed: D58.2 (A), SW_58.2
unnamed: D59.2 (A), SW_59.2
unnamed: D60.2 (A), SW_60.2
unnamed: D61.2 (A), SW_61.2
unnamed: D62.2 (A), SW_62.2
unnamed: D63.2 (A), SW_63.2
unnamed: D64.2 (A), SW_64.2
unnamed: D65.2 (A), SW_65.2
unnamed: D66.2 (A), SW_66.2
unnamed: D67.2 (A), SW_67.2
unnamed: D68.2 (A), SW_68.2
unnamed: D69.2 (A), SW_69.2
unnamed: D70.2 (A), SW_70.2
unnamed: D71.2 (A), SW_71.2
unnamed: D72.2 (A), SW_72.2
unnamed: D73.2 (A), SW_73.2
unnamed: D74.2 (A), SW_74.2
unnamed: D75.2 (A), SW_75.2
unnamed: D76.2 (A), SW_76.2
unnamed: D77.2 (A), SW_77.2
unnamed: D78.2 (A), SW_78.2
unnamed: D79.2 (A), SW_79.2
unnamed: D80.2 (A), SW_80.2
unnamed: D81.2 (A), SW_81.2
unnamed: D82.2 (A), SW_82.2
unnamed: D83.2 (A), SW_83.2
unnamed: D84.2 (A), SW_84.2
unnamed: LED1.1 (DOUT), LED2.3 (DIN)
unnamed: LED2.1 (DOUT), LED3.3 (DIN)
unnamed: LED3.1 (DOUT), LED4.3 (DIN)
unnamed: LED4.1 (DOUT), LED5.3 (DIN)
unnamed: LED5.1 (DOUT), LED6.3 (DIN)
unnamed: LED6.1 (DOUT), LED7.3 (DIN)
unnamed: LED7.1 (DOUT), LED8.3 (DIN)
unnamed: LED8.1 (DOUT), LED9.3 (DIN)
unnamed: LED9.1 (DOUT), LED10.3 (DIN)
unnamed: LED10.1 (DOUT), LED11.3 (DIN)
unnamed: LED11.1 (DOUT), LED12.3 (DIN)
unnamed: LED13.1 (DOUT), LED14.3 (DIN)
unnamed: LED14.1 (DOUT), LED15.3 (DIN)
unnamed: LED15.1 (DOUT), LED16.3 (DIN)
unnamed: LED16.1 (DOUT), LED17.3 (DIN)
unnamed: LED17.1 (DOUT), LED18.3 (DIN)
unnamed: LED18.1 (DOUT), LED19.3 (DIN)
unnamed: LED19.1 (DOUT), LED20.3 (DIN)
unnamed: LED20.1 (DOUT), LED21.3 (DIN)
unnamed: LED21.1 (DOUT), LED22.3 (DIN)
unnamed: LED22.1 (DOUT), LED23.3 (DIN)
unnamed: LED23.1 (DOUT), LED24.3 (DIN)
unnamed: LED25.1 (DOUT), LED26.3 (DIN)
unnamed: LED26.1 (DOUT), LED27.3 (DIN)
unnamed: LED27.1 (DOUT), LED28.3 (DIN)
unnamed: LED28.1 (DOUT), LED29.3 (DIN)
unnamed: LED29.1 (DOUT), LED30.3 (DIN)
unnamed: LED30.1 (DOUT), LED31.3 (DIN)
unnamed: LED31.1 (DOUT), LED32.3 (DIN)
unnamed: LED32.1 (DOUT), LED33.3 (DIN)
unnamed: LED33.1 (DOUT), LED34.3 (DIN)
unnamed: LED34.1 (DOUT), LED35.3 (DIN)
unnamed: LED35.1 (DOUT), LED36.3 (DIN)
unnamed: LED37.1 (DOUT), LED38.3 (DIN)
unnamed: LED38.1 (DOUT), LED39.3 (DIN)
unnamed: LED39.1 (DOUT), LED40.3 (DIN)
unnamed: LED40.1 (DOUT), LED41.3 (DIN)
unnamed: LED41.1 (DOUT), LED42.3 (DIN)
unnamed: LED42.1 (DOUT), LED43.3 (DIN)
unnamed: LED43.1 (DOUT), LED44.3 (DIN)
unnamed: LED44.1 (DOUT), LED45.3 (DIN)
unnamed: LED45.1 (DOUT), LED46.3 (DIN)
unnamed: LED46.1 (DOUT), LED47.3 (DIN)
unnamed: LED47.1 (DOUT), LED48.3 (DIN)
unnamed: LED49.1 (DOUT), LED50.3 (DIN)
unnamed: LED50.1 (DOUT), LED51.3 (DIN)
unnamed: LED51.1 (DOUT), LED52.3 (DIN)
unnamed: LED52.1 (DOUT), LED53.3 (DIN)
unnamed: LED53.1 (DOUT), LED54.3 (DIN)
unnamed: LED54.1 (DOUT), LED55.3 (DIN)
unnamed: LED55.1 (DOUT), LED56.3 (DIN)
unnamed: LED56.1 (DOUT), LED57.3 (DIN)
unnamed: LED57.1 (DOUT), LED58.3 (DIN)
unnamed: LED58.1 (DOUT), LED59.3 (DIN)
unnamed: LED59.1 (DOUT), LED60.3 (DIN)
unnamed: LED61.1 (DOUT), LED62.3 (DIN)
unnamed: LED62.1 (DOUT), LED63.3 (DIN)
unnamed: LED63.1 (DOUT), LED64.3 (DIN)
unnamed: LED64.1 (DOUT), LED65.3 (DIN)
unnamed: LED65.1 (DOUT), LED66.3 (DIN)
unnamed: LED66.1 (DOUT), LED67.3 (DIN)
unnamed: LED67.1 (DOUT), LED68.3 (DIN)
unnamed: LED68.1 (DOUT), LED69.3 (DIN)
unnamed: LED69.1 (DOUT), LED70.3 (DIN)
unnamed: LED70.1 (DOUT), LED71.3 (DIN)
unnamed: LED71.1 (DOUT), LED72.3 (DIN)
unnamed: LED73.1 (DOUT), LED74.3 (DIN)
unnamed: LED74.1 (DOUT), LED75.3 (DIN)
unnamed: LED75.1 (DOUT), LED76.3 (DIN)
unnamed: LED76.1 (DOUT), LED77.3 (DIN)
unnamed: LED77.1 (DOUT), LED78.3 (DIN)
unnamed: LED78.1 (DOUT), LED79.3 (DIN)
unnamed: LED79.1 (DOUT), LED80.3 (DIN)
unnamed: LED80.1 (DOUT), LED81.3 (DIN)
unnamed: LED81.1 (DOUT), LED82.3 (DIN)
unnamed: LED82.1 (DOUT), LED83.3 (DIN)
unnamed: LED83.1 (DOUT), LED84.3 (DIN)
RGB: A1.31 (GPIO26_ADC0), LED1.3 (DIN)
RGB_1: LED12.1 (DOUT), LED13.3 (DIN)
RGB_2: LED24.1 (DOUT), LED25.3 (DIN)
RGB_3: LED36.1 (DOUT), LED37.3 (DIN)
RGB_4: LED48.1 (DOUT), LED49.3 (DIN)
RGB_5: LED60.1 (DOUT), LED61.3 (DIN)
RGB_6: LED72.1 (DOUT), LED73.3 (DIN)
ROW0: A1.22 (GPIO17), D74.1 (K), D75.1 (K), D76.1 (K), D77.1 (K), D78.1 (K), D79.1 (K), D80.1 (K), D81.1 (K), D82.1 (K), D83.1 (K), D84.1 (K)
ROW1: A1.24 (GPIO18), D61.1 (K), D62.1 (K), D63.1 (K), D64.1 (K), D65.1 (K), D66.1 (K), D67.1 (K), D68.1 (K), D69.1 (K), D70.1 (K), D71.1 (K), D72.1 (K), D73.1 (K)
ROW2: A1.25 (GPIO19), D48.1 (K), D49.1 (K), D50.1 (K), D51.1 (K), D52.1 (K), D53.1 (K), D54.1 (K), D55.1 (K), D56.1 (K), D57.1 (K), D58.1 (K), D59.1 (K), D60.1 (K)
ROW3: A1.26 (GPIO20), D31.1 (K), D32.1 (K), D33.1 (K), D34.1 (K), D35.1 (K), D36.1 (K), D37.1 (K), D38.1 (K), D39.1 (K), D40.1 (K), D41.1 (K), D42.1 (K), D43.1 (K), D44.1 (K), D45.1 (K), D46.1 (K), D47.1 (K)
ROW4: A1.27 (GPIO21), D14.1 (K), D15.1 (K), D16.1 (K), D17.1 (K), D18.1 (K), D19.1 (K), D20.1 (K), D21.1 (K), D22.1 (K), D23.1 (K), D24.1 (K), D25.1 (K), D26.1 (K), D27.1 (K), D28.1 (K), D29.1 (K), D30.1 (K)
ROW5: A1.29 (GPIO22), D1.1 (K), D2.1 (K), D3.1 (K), D4.1 (K), D5.1 (K), D6.1 (K), D7.1 (K), D8.1 (K), D9.1 (K), D10.1 (K), D11.1 (K), D12.1 (K), D13.1 (K)

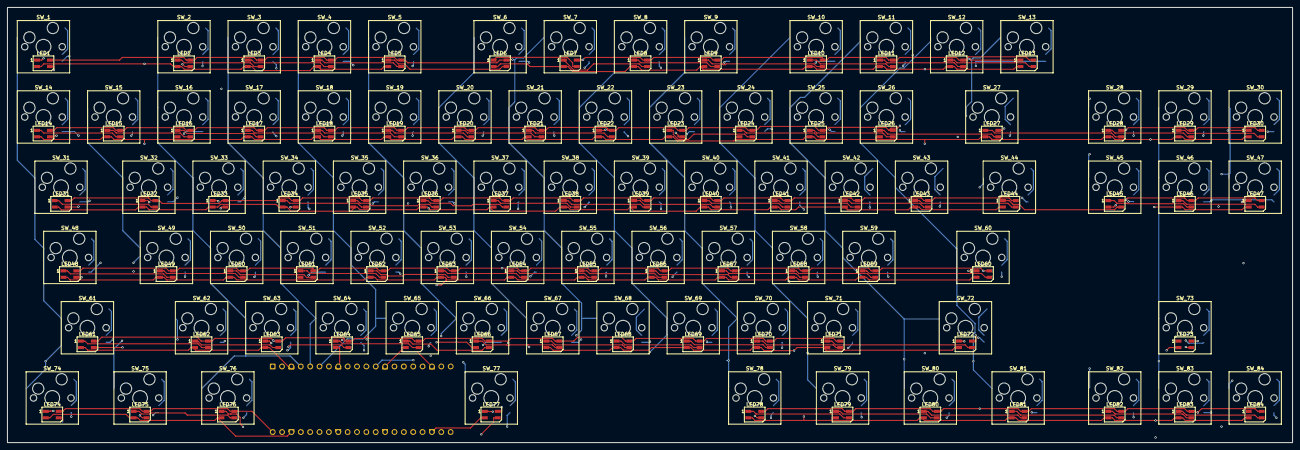
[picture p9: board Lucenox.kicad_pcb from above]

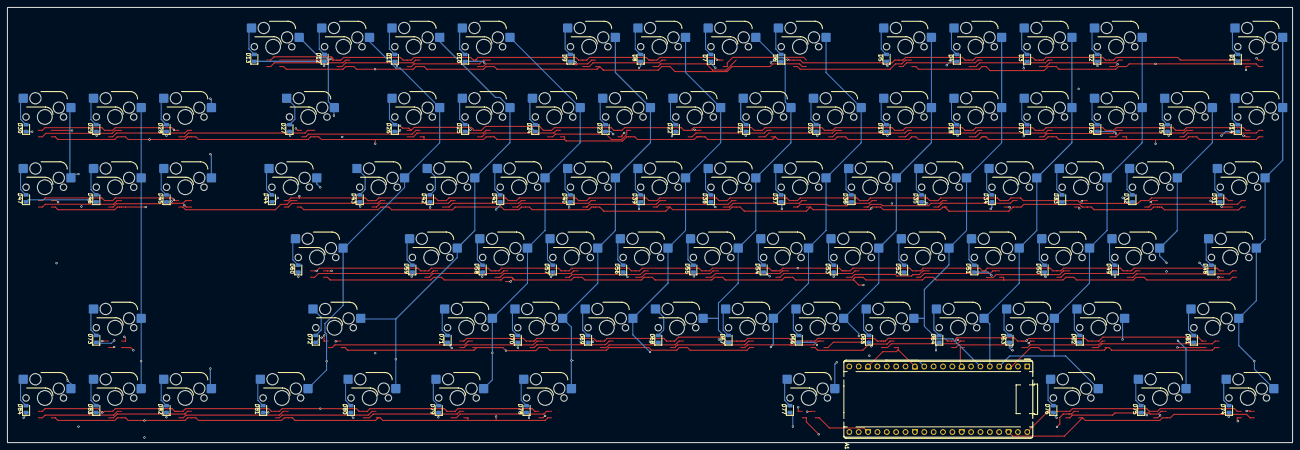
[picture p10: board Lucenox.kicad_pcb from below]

Board: 4 copper layers, 348.5 x 118.0 mm, 253 parts (85 on the bottom side), 193 nets.

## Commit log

2025-06-23 Add project files
    [BOM.csv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]
2025-07-24 Finish BOM and CAD Model
    [Case.step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]
2025-07-24 Finish BOM as csv
    [BOM.csv]
2025-07-24 Update BOM.csv to include Euro symbol in price column
    [BOM.csv]
2025-07-24 Cheaper LCSC fees but 4€ kailh socket shipping
    [BOM.csv]
2025-07-24 PCB costs more than expected
    [BOM.csv]
